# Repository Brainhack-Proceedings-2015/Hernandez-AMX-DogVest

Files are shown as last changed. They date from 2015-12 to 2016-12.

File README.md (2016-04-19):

# DogVest

## Project Description

In this project we designed a low cost and easy build device to register
important physiological variables that can be used to study in a non-invasive
manner dog’s cognition.

## File structure

### Report
File				| Description
--------------------------------|----------------------
brainhack-report.md		| Report markdown file
brainhack-report-formatted.tex  | TeX output file
figure1.pdf			| Report Figure
brainhack-report.bib		| Report Bibliography
brainhack-report-formatted.pdf	| Report Output File

### Report Templates

* bhgn.pdf               
* bmcart.cls            
* bmc-mathphys.bst 
* bmcart-biblio.sty 
* brainhack-report-template.tex

> [Source](https://github.com/ccraddock/brainhack_reports)

### Scripts

Directory of the libraries and and arduino scripts

<br /><span xmlns:dct="http://purl.org/dc/terms/" property="dct:title">Dogvest</span> by <a xmlns:cc="http://creativecommons.org/ns#" href="http://www.inb.unam.mx/" property="cc:attributionName" rel="cc:attributionURL">Instituto de Neurobiología, UNAM</a> is licensed under a <a rel="license" href="http://creativecommons.org/licenses/by/4.0/">Creative Commons Attribution 4.0 International License</a>.<br />Based on a work at <a xmlns:dct="http://purl.org/dc/terms/" href="https://github.com/nekrum/DogVest" rel="dct:source">https://github.com/nekrum/DogVest</a>.

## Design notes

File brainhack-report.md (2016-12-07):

---
event: '2015 Brainhack Americas (MX)'

title:  "Open source low-cost device to register dog's heart rate and tail movement"

author:

- initials: RH
  surname: Hernández-Pérez
  firstname: Raúl
  email: raul@lafuentelab.org
  affiliation: aff1
- initials: EAM
  surname: Morales
  firstname: Edgar A.
  email: edalvmor@yahoo.com.mx
  affiliation: aff1
- initials: LVC
  surname: Cuaya
  firstname: Laura V.
  email: lauveri.rozen@gmail.com
  affiliation: aff1
  corref: aff1

affiliations: 

- id: aff1
  orgname: 'Instituto de Neurobiología'
  street: Boulevard Juriquilla 3001
  postcode: 76230
  city: Queretaro
  state: Queretaro
  country: Mexico

url: https://github.com/nekrum/DogVest

coi: None

acknow: "We would like to thank the organizers and attendees of Brainhack MX and to the Instituto de Neurobiología. Specially to Fernando Barrios Alvarez for the invitation and the support on the realization of the project.
Laura V. Cuaya, Raul Hernández and Edgar Morales are a doctoral students from Programa de Doctorado en Ciencias Biomédicas, Universidad Nacional Autónoma de México (UNAM) and received fellowship 407590, 409258 and 215702 from CONACYT."

contrib: LVC generated the idea for the project, made the research, help writing the report and acquire the data. EAM and RH designed the device, build it, wrote the code and help writing the report.
  
bibliography: brainhack-report

gigascience-ref: \href{http://gigadb.org/dataset/100228}{doi:10.5524/100228}
...

# Introduction

In dogs, the perception of an important stimulus can be related to 
physiological changes such as the heart rate (e.g., in socioemotional situations
 with humans \cite{Palestrini200575} or dogs \cite{Siniscalchi20132279} ) and the movement of their tail (for example, tail-wagging
 has a bias that depends on the nature of the stimulus, a bias to the left is 
related to a withdrawal tendency and a bias to the right is related to an approach
 tendency \cite{Quaranta2007R199} ). 

Although heart rate and the tail movement are important gateways to understanding
dog cognition, just a few studies report these variables. Perhaps this is
related to the difficulty of obtaining records of these variables in natural
environments (e.g., parks), the elevated cost of commercial data aquisition
hardware (around $5,000 USD \cite{paragonURL} )  or by nonexistence of a tail-movement
registering device. For these reasons, the goal of this brainhack project is to
design and build a low cost device able to register the heart rate and changes
in the tail movement in dogs, both in laboratory and in free movement
conditions.

# Approach

We decided to base our design in arduino hardware for its accessibility and
broad use. The materials are detailed in the Table \ref{materialstable}.

\begin{table*}[t!]
\caption{\label{materialstable} Materials and cost. The table shows most of the materials used and their approximated cost with a local provider. Other materials were used but their cost is negligible.}
\begin{tabular}{l l}
 \hline\noalign{\smallskip}
   Materials  & Aproximated cost (in USD) \\
    \hline\noalign{\smallskip}
  Arduino UNO rev3   				& 20    \\
  EKG-EMG-shield from Olimex with electrodes    & 48    \\
  Vibration sensor from phidgets    		& 11    \\
  9v rechargeable battery    			& 7	\\
  SD Card Reader module ARM MCU    		& 1.2   \\
  Total    					& 87.2  \\
  \noalign{\smallskip}\hline
\end{tabular}
\end{table*}

We designed and 3d printed a PLA case to contain the circuit. The case has a
slot to add a strap to fix the device on the dogs back. The program for the
arduino and the model for the case can be downloaded from the GitHub (scripts directory)
repository of the project.

In order to assess if the device could reliably get readings from a dog, we
tested it in three phases: baseline, stimulation/no-stimulation and free
movement. All phases lasted two minutes and were repeated twice on two dogs. In
both, baseline and stimulation/no-stimulation, the dog stayed in sphinx position
without movement restrictions but under the command “stay”. The
stimulation/no-stimulation phase consisted in three interleaved repetitions of
two types of conditions, stimulation and no-stimulation, each repetition lasted
20 s. In the stimulation condition the dog owner showed the dog a treat and
mentioned the dog’s name. In the free movement condition, the dog walked down a
street without any specific command.

# Results

In the stimulation/no-stimulation phase a  Wilcoxon Signed Rank Test revealed
statistically significant differences (p < 0.05) between the beats per minute,
beat amplitude and the tail movement amplitude (Figure \ref{centfig}).

\begin{figure}[h!]
  \includegraphics[width=.47\textwidth]{figure1}
  \caption{\label{centfig}
The results shown were obtained from two dogs under two consecutive conditions. Stimulation and No-stimulation. In panels A), B) and C), the colors represent the conditions. The panel A) represents the standard deviation from the mean of the heart beat amplitude. The panel B) represents the change on the beats per minute on both conditions minus a baseline registered directly from each dog. The vertical lines represent the standard error. The panel C) represents the standard deviation from the mean of the tail movement. The panel D) shows one of the registered dogs wearing the device.
}
\end{figure}

By matching the data collected with observations of the movement of the tail, we
notice that the data reflects the position of the tail but its resolution
depended on the position of the electrode.

The data acquire from the free movement condition was affected by the movement
and did not seem reliable for testing.

# Conclusions

We were able to build and test a non-invasive low cost device with the capacity
to register the heart rate and the tail movement of dogs. We consider that the
addition of a movement sensor could provide additional data to reduce the change
on the signal due to movement.

This device can be integrated in future research on dog cognition. It can also
be used in shelters and homes to easily measure the responses that dogs present
to different sets of stimuli; for example, when a dog is left alone in its house
and shows stress (i.e. increased heart rate, preferential tail movement to the
left) the dog’s carer could make changes in the environment to increase the
well-being of the dog.

The low cost and the easy access to the materials needed to build the device
make it a feasible option to study dog cognition. The results showed that the
device could be used to distinguish between two different stimulation
conditions.

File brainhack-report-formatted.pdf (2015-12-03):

Hern´andez-P´erez et al.

110110110111000111001101101101101110001110011011011011011100011100110110110110111000111001101101101101110001110011011011011011100011100110110110110111000111001101101101101110001110011011011011011100011100110110110110111000111001101101101101 110001110011011011011011100011100110110110110111000111001101101101101110001110011011011011011100011100110110110110111000111001101101101101110001110011011011011011100011100110110110110111000111001101101101101110001110011011011011011100011100 110110110110111000111001101101101101110001110011011011011011100011100110110110110111000111001101101101101110001110011011011011011100011100110110110110111000111001101101101101110001110011011011011011100011100110110110110111000111001101101101 101110001110011011011011011100011100110110110110111000111001101101101101110001110011011011011011100011100110110110110111000111001101101101101110001110011011011011011100011100110110110110111000111001101101101101110001110011011011011011100011 100110110110110111000111001101101101101110001110011011011011011100011100110110110110111000111001101101101101110001110011011011011011100011100110110110110111000111001101101101101110001110011011011011011100011100110110110110111000111001101101 101101110001110011011011011011100011100110110110110111000111001101101101101110001110011011011011011100011100110110110110111000111001101101101101110001110011011011011011100011100110110110110111000111001101101101101110001110011011011011011100 011100110110110110111000111001101101101101110001110011011011011011100011100110110110110111000111001101101101101110001110011011011011011100011100110110110110111000111001101101101101110001110011011011011011100011100110110110110111000111001101 101101101110001110011011011011011100011100110110110110111000111001101101101101110001110011011011011011100011100110110110110111000111001101101101101110001110011011011011011100011100110110110110111000111001101101101101110001110011011011011011 100011100110110110110111000111001101101101101110001110011011011011011100011100110110110110111000111001101101101101110001110011011011011011100011100110110110110111000111001101101101101110001110011011011011011100011100110110110110111000111001 101101101101110001110011011011011011100011100110110110110111000111001101101101101110001110011011011011011100011100110110110110111000111001101101101101110001110011011011011011100011100110110110110111000111001101101101101110001110011011011011 011100011100110110110110111000111001101101101101110001110011011011011011100011100110110110110111000111001101101101101110001110011011011011011100011100110110110110111000111001101101101101110001110011011011011011100011100110110110110111000111 001101101101101110001110011011011011011100011100110110110110111000111001101101101101110001110011011011011011100011100110110110110111000111001101101101101110001110011011011011011100011100110110110110111000111001101101101101110001110011011011 011011100011100110110110110111000111001101101101101110001110011011011011011100011100110110110110111000111001101101101101110001110011011011011011100011100110110110110111000111001101101101101110001110011011011011011100011100110110110110111000 111001101101101101110001110011011011011011100011100110110110110111000111001101101101101110001110011011011011011100011100110110110110111000111001101101101101110001110011011011011011100011100110110110110111000111001101101101101110001110011011 011011011100011100110110110110111000111001101101101101110001110011011011011011100011100110110110110111000111001101101101101110001110011011011011011100011100110110110110111000111001101101101101110001110011011011011011100011100110110110110111 000111001101101101101110001110011011011011011100011100110110110110111000111001101101101101110001110011011011011011100011100110110110110111000111001101101101101110001110011011011011011100011100110110110110111000111001101101101101110001110011 011011011011100011100110110110110111000111001101101101101110001110011011011011011100011100110110110110111000111001101101101101110001110011011011011011100011100110110110110111000111001101101101101110001110011011011011011100011100110110110110 111000111001101101101101110001110011011011011011100011100110110110110111000111001101101101101110001110011011011011011100011100110110110110111000111001101101101101110001110011011011011011100011100110110110110111000111001101101101101110001110 011011011011011100011100110110110110111000111001101101101101110001110011011011011011100011100110110110110111000111001101101101101110001110011011011011011100011100110110110110111000111001101101101101110001110011011011011011100011100110110110

# brainhack

# Report from 2015 Brainhack Americas (MX)

# Open source low-cost device to register dog’s heart rate and tail movement

# Project URL: https://github.com/nekrum/DogVest

# Ra´ul Hern´andez-P´erez* , Edgar A. Morales and Laura V. Cuaya

# 1 Introduction

# In dogs, the perception of an important stimulus can be related to physiological changes such as the heart rate (e.g., in socioemotional situations with humans

[1] or dogs [2] ) and the movement of their tail (e.g.,

# tail-wagging has a bias that depends on the nature of the stimulus, a bias to the left is related to a withdrawal tendency and a bias to the right is related to

an aproach tendency [3] ).

Altough heart rate and the tail movement are important gateways to understand dog’s cognition, just a few studies report these variables. Perhaps this is related to the difficulty of obtaining records of these variables in natural enviroments (e.g., parks), the elevated cost of a commercial data adquisition hardware (around $5,000 USD [4] ) or by inexistence of a tailmovement registering device. For these reasons, the goal of this brainhack project is to design and build a low cost device able to register the heart rate and changes in the tail movement in dogs, both in labora-

tory and in free movement conditions.

# 2 Approach

# We decided to base our design in arduino hardware for its accessibility and broad use. The materials are

detailed in the Table 1.

# We designed and 3d printed a PLA case to contain the circuit. The case has a slot to add a strap to fix the device on the dogs back. The program for the arduino and the model for the case can be downloaded from the

GitHub (scripts directory) repository of the project.

### *Correspondence: raul@lafuentelab.org

Instituto de Neurobiolog´ıa, Queretaro, Boulevard Juriquilla 3001, 76230,

### Queretaro, Mexico Full list of author information is available at the end of the article

In order to asses if the device could reliably get readings from a dog, we tested it in three phases: baseline, stimulation/no-stimulation and free movement. All phases lasted two minutes and were repeated twice on two dogs. In both, baseline and stimulation/no-stimulation, the dog stayed in sphinx position without movement restrictions but under the command “stay”. The stimulation/no-stimulation phase consisted in three interleaved repetitions of two

types of conditions, stimulation and no-stimulation,

# each repetition lasted 20 s. In the stimulation condition the dog owner showed the dog a treat and mention the dog’s name. In the free movement condition, the dog

walked down a street without any specific command.

# 3 Results

# In the stimulation/no-stimulation phase a Wilcoxon Signed Rank Test revealed statistically significant differences (p < 0.05) between the beats per minute, beat amplitude and the tail movement amplitude (Figure

1).

# By matching the data collected with observations of the movement of the tail, we notice that the data reflects the position of the tail but its resolution de-

pended on the position of the electrode.

# The data acquire from the free movement condition was affected by the movement and didn’t seem reliable

for testing.

# 4 Conclusions

# We were able to build and test a non-invasive low cost device with the capacity to register the heart rate and the tail movement of dogs. We consider that the addition of a movement sensor could provide additional data to reduce the change on the signal due to move-

ment.

Hern´andez-P´erez et al. | Page 2 of 2

Table 1 Materials and cost. The table shows most of the materials used and their approximated cost with a local provider. Other materials were used but their cost is negligible.

Materials | Aproximated cost (in USD)
Arduino UNO rev3 | 20
EKG-EMG-shield from Olimex with electrodes | 48
Vibration sensor from phidgets | 11
9v rechargeable battery | 7
SD Card Reader module ARM MCU | 1.2
Total | 87.2

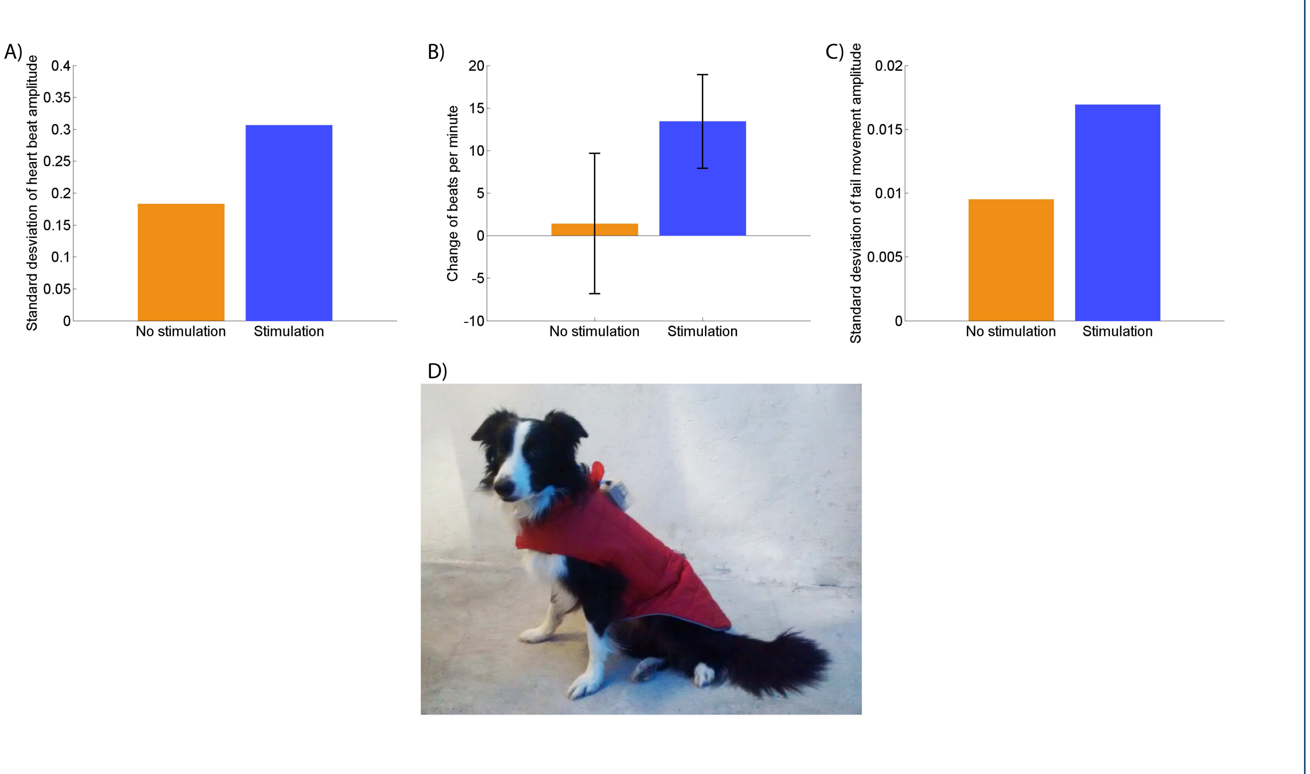
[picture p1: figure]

Figure 1 The results shown were obtained from two dogs under two consecutive conditions. Stimulation and No-stimulation. In panels A), B) and C), the colors represent the conditions. The panel A) represents the standard deviation from the mean of the heart beat amplitude. The panel B) represents the change on the beats per minute on both

conditions minus a baseline registered directly from each dog.

## The vertical lines represent the standard error. The panel C) represents the standard deviation from the mean of the tail movement. The panel D) shows one of the registered dogs

wearing the device.

This device can be integrated in future research on dog’s cognition. It can also be used in shelters and homes to easily measure the responses that dogs present to different sets of stimuli; for example, when a dog is left alone in its house and shows stress (i.e. increased heart rate, preferential tail movement to the left) the dog’s carer could make changes in the envi-

ronment to increase the well-being of the dog.

# The low cost and the easy access to the materials needed to build the device make it a feasible option to study dog cognition. The results showed that the device could be used to distinguish between two different

stimulation conditions.

### Availability of Supporting Data

### More information about this project can be found at: https://github.com/nekrum/DogVest. Further data and files supporting

this project are hosted in the GigaScience repository REFXXX.

### Competing interests

### None

### Author’s contributions LVC generated the idea for the project, made the research, help writing the

report and acquire the data. EAM and RH designed the device, build it, wrote the code and help writing the report.

### Acknowledgements We would like to thank the organizers and attendees of Brainhack MX and to the Instituto de Neurobiolog´ıa. Specially to Fernando Barrios Alvarez for

the invitation and the support on the realization of the project. Laura V.

### Cuaya, Raul Hern´andez and Edgar Morales are a doctoral students from Programa de Doctorado en Ciencias Biom´edicas, Universidad Nacional Aut´onoma de M´exico (UNAM) and received fellowship 407590, 409258 and

215702 from CONACYT.

### References 1. Palestrini, C., Previde, E.P., Spiezio, C., Verga, M.: Heart rate and behavioural responses of dogs in the ainsworth’s strange situation: A

pilot study. Applied Animal Behaviour Science 94(1–2), 75–88 (2005).

### doi:10.1016/j.applanim.2005.02.005 (http://dx.doi.org/10.1016/j.applanim.2005.02.005) 2. Siniscalchi, M., Lusito, R., Vallortigara, G., Quaranta, A.: Seeing left- or right-asymmetric tail wagging produces different emotional responses in

dogs. Current Biology 23(22), 2279–2282 (2013).

### doi:10.1016/j.cub.2013.09.027 (http://dx.doi.org/10.1016/j.cub.2013.09.027) 3. Quaranta, A., Siniscalchi, M., Vallortigara, G.: Asymmetric tail-wagging

responses by dogs to different emotive stimuli. Current Biology 17(6), 199–201 (2007). doi:10.1016/j.cub.2007.02.008 (http://dx.doi.org/10.1016/j.cub.2007.02.008)
4. SUPPLY, P.M.: Vmed Bluetooth Wireless Veterinary Monitors. http://www.paragonmed.com/wirelessmonitors.shtml. [Online;

### accessed 02-Dicember-2015] (2014)

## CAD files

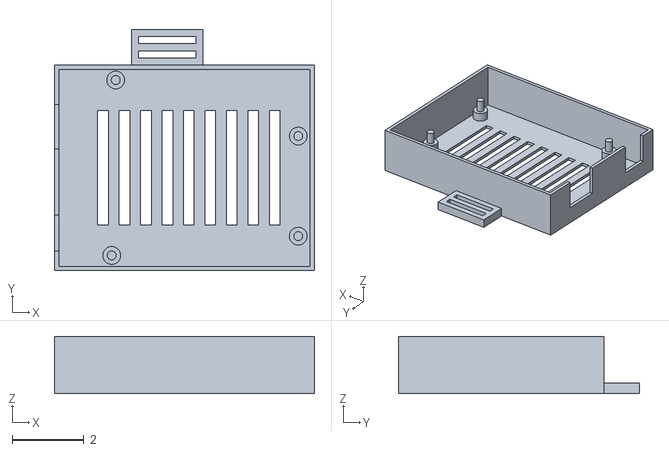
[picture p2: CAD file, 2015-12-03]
scripts/arduinoBase.stl
7.26 x 6.74 x 1.60

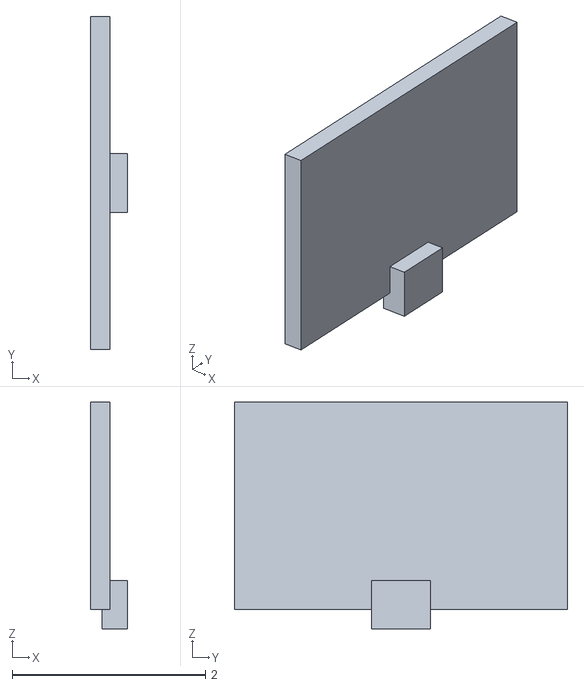
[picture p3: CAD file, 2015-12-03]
scripts/batteryCover.stl
0.38 x 3.45 x 2.35

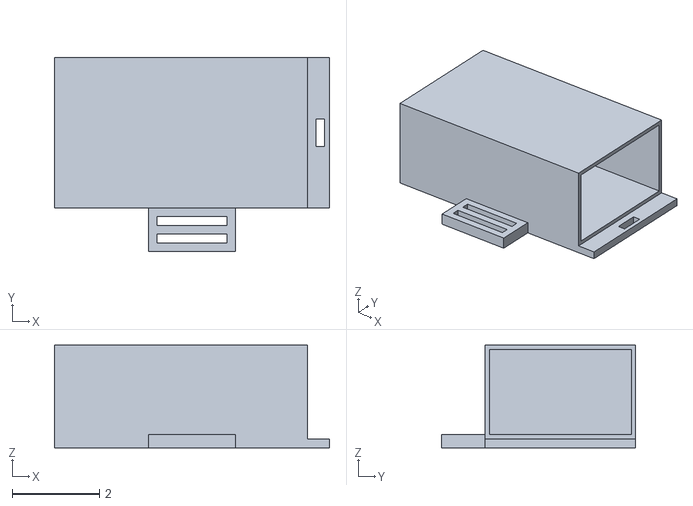
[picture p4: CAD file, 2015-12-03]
scripts/batteryCase.stl
6.30 x 4.45 x 2.35

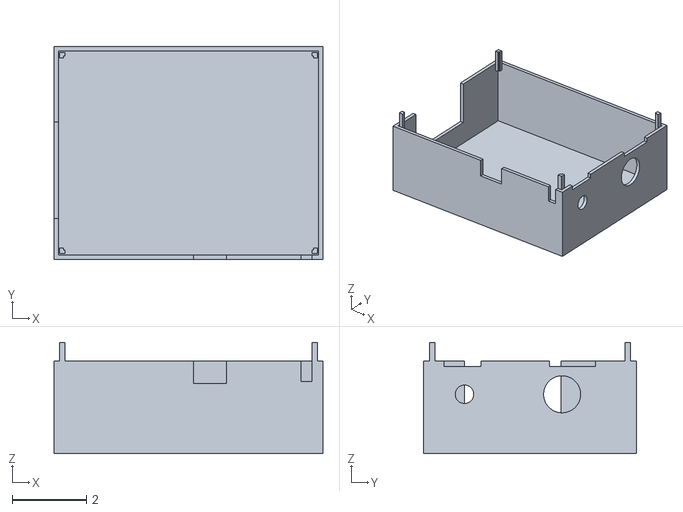
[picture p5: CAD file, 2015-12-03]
scripts/arduinoCover.stl
7.26 x 5.74 x 3.00

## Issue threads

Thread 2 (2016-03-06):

Please include description of principle features and implementation

hanke, 2016-03-06:
The report talks about the device's capability to capture heart rate and tail movement. However, no description is given on how this information is captured. The only hint is given in the table with the component list. For someone not familiar with the arduino platform or with those components it would be very helpful to give a compact description on what role each component has, and how they all work together.

For someone wanting to build such a device it would also be very helpful to indicate with features provided by each component were critical. I assume that there are alternatives that would work equally well and may be better accessible/available elsewhere or in the future.

nekrum, 2016-04-08:
In the Pull Request  #7 line 233 the Arduino and EKG-EMG-shield features are described, also line 325 add more details to implementation of the devices.

hanke, 2016-05-06:
Thanks for the change!

Closed 2016-05-06.

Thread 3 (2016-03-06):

Please give indication on the nature of the data output

hanke, 2016-03-06:
The actual arduino code is relatively compact and naturally seems to be focused on data capture. Please give some indication on the nature of the output data of the device. How many/which sensor outputs, sampling rate, data format (text/binary), and maybe how it can/must be further processed. Essentially all  information that is necessary to produce something like the plots in the manuscript.

nekrum, 2016-04-08:
Pull Request #7 line 267, describe the nature of the data output and some details of the data format.

hanke, 2016-05-06:
Thanks!

Closed 2016-05-06.

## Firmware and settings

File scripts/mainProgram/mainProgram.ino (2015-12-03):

#include <FlexiTimer2.h>
#include <SPI.h>
#include <SD.h>

// Vars
File counterFile;
File dataF;
#define LED1 7 // this pin flashes to indicate the moment of the recording
#define SAMPLETIME 120000 //In ms
#define TIMER2VAL 100 //Time between samples
#define SAMPLES SAMPLETIME/TIMER2VAL
unsigned int counter = 1;
unsigned int recording = 0;
const int buttonPin = 2;     // the number of the pushbutton pin
const int ledPin =  4;      // number of pin that would indicate recording
unsigned int numOfFile;
char numOfFileC;
String valStr;
volatile unsigned char CurrentCh;
volatile unsigned int ADC_Value = 0; 
//unsigned int analogAr[6];

// Functions

//record gets data from the sensors and both records it in the SD and sends it trough serial
void record(void)
{
  recording = 1;
  valStr = String(counter);
  for(CurrentCh=0;CurrentCh<6;CurrentCh++)
  {
    
    ADC_Value = analogRead(CurrentCh);
    valStr += "," + String(ADC_Value);
    //valStr = "At indx" + String(CurrentCh) + " the value is " + String(ADC_Value) + "\n";
  }
  Serial.println(valStr); //prints new line on serial
  dataF.println(valStr); //prints new line on file
  
  
  static boolean output = HIGH;
  digitalWrite(LED1, output);
  output = !output;
  counter++;
  if(counter > SAMPLES)
  {
    FlexiTimer2::stop();
    recording = 0;
    Toggle_LED3(recording);
    
    dataF.close(); // closes file
    Serial.print("File recorded\n");
    Serial.print("Waiting for button\n");
  }
}

void Toggle_LED3(int state) //LED that indicates that the device is recording
{
  if (state == 1)
  {
    digitalWrite(ledPin, HIGH);
    Serial.print("On\n");
  }
  else
  {
    digitalWrite(ledPin, LOW);
    Serial.print("Off\n");
  }
  
}



void setup() //initual setup
{
  Serial.begin(57600); //starts serial
  //Starts SD card, if fails, stops program
  if (!SD.begin(10)) 
  {
    Serial.println("initialization failed!");
    return;
  }
  
  
  

  // put your setup code here, to run once:
  pinMode(LED1, OUTPUT);  //Setup LED1 direction
  pinMode(buttonPin, INPUT);  //Setup button direction
  //digitalWrite(buttonPin,LOW);
  digitalWrite(LED1,LOW); //Setup LED1 state
  pinMode(ledPin, OUTPUT);  //Setup LED3 direction
  digitalWrite(ledPin,LOW); //Setup LED3 state

  FlexiTimer2::set(TIMER2VAL, record);
  recording = 0;
  Serial.print("Waiting for button\n");
  
}

void loop() 
{
  //Serial.print(digitalRead(buttonPin));
  //Serial.print(recording);
  if (recording == 0)
  {
    //Serial.print("Recording is 0");
    if (digitalRead(buttonPin))
    {
      
      // Continues with the count of the file
      Serial.print("Opening file");
      counterFile = SD.open("0FILE.txt");
      Serial.print("File opened");
      numOfFile = counterFile.parseInt() + 1;
      Serial.print("Last number of file is: " + String(numOfFile-1) + "\n");
      counterFile.close();
      SD.remove("0FILE.txt");
      Serial.print("Adding number of file\n");
      counterFile = SD.open("0FILE.txt", FILE_WRITE);
      counterFile.println(String(numOfFile));
      counterFile.close();
      // Finishes counting the file

      // Opens new file
      Serial.print("Creating file " + String(numOfFile) + "\n");
      dataF = SD.open("F" + String(numOfFile) + ".csv", FILE_WRITE);
      

      
      recording = 1;
      counter = 1;
      Toggle_LED3(recording);
      FlexiTimer2::start();
      while (digitalRead(buttonPin))
      {
        //Serial.print(digitalRead(buttonPin));
      }
    }
  }
  else
  {
    //Serial.print("Button pressed\n");
    if (!digitalRead(buttonPin))
    {
      while (recording == 1)
      {
        //Serial.print(digitalRead(buttonPin));
        delay(1);
        //Serial.print(recording);
      }
    }
  }
}
  

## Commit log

2015-12-03 mainProgram scripts and libraries, and main files
    [arduinoBase.stl, arduinoCover.stl, batteryCase.stl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]
2016-04-07 Agregadas las licencias de software y paper, modificaciones de texto y nuevos outputs
